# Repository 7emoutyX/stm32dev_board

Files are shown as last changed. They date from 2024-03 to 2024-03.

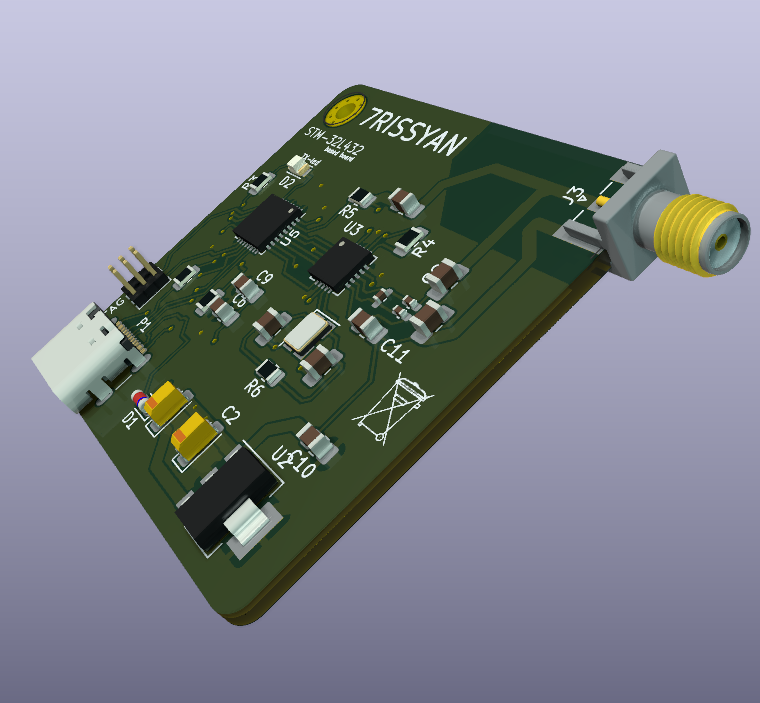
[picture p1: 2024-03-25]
Final results/33.png

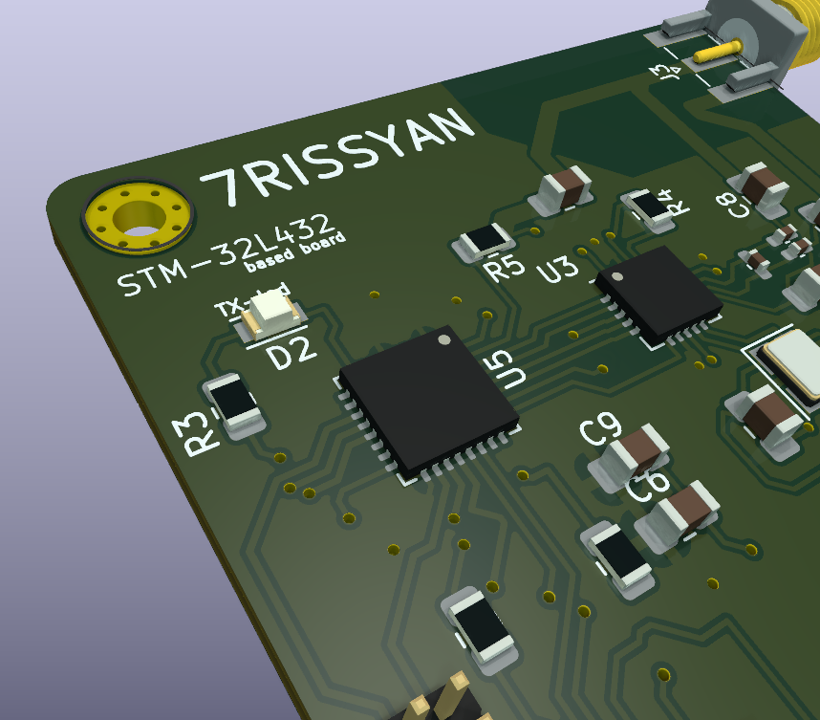
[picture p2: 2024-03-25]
Final results/44.png

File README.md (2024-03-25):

 STM32L432KBU_NRF24L01P_Development_Board

## Overview
This repository contains the KiCad project files and firmware source code for the STM32L432KBU development board integrated with the NRF24L01P module. 

## Schematic 
Final Schematic

[Download Schematic.pdf](https://github.com/7emoutyX/stm32dev_board/files/14748390/Final.Schematic.pdf)

## Layaout :  
Layaout with Fill : OFF
Layaout with Fill : ON

## Features
- Development board based on STM32L432KBU microcontroller
- Integrated NRF24L01P wireless communication module
- Antenna socket
- JTAG debug pins
- Schematics and PCB layout designed with KiCad

## Getting Started
To get started with this development board, follow these steps:

1. Clone this repository to your local machine.
2. Open the KiCad project files located in the `Documentation/Schematics` and `Documentation/PCB Layout` directories.
3. Review the schematics and PCB layout to understand the hardware design.

## Documentation
- **Schematics:** KiCad schematic files (.sch)
- **PCB Layout:** KiCad PCB layout files (.kicad_pcb)
- **Datasheets:**:
- Datasheets for STM32L432KBU : (https://www.mouser.fr/datasheet/2/389/stm32l432kb-1851151.pdf)
- Datasheets NRF24L01P  : (https://www.mouser.fr/datasheet/2/297/nRF24L01P-1187709.pdf)

## Issues
Found a bug or have a feature request? Please open an issue [here](../../issues)!

## Final results : 



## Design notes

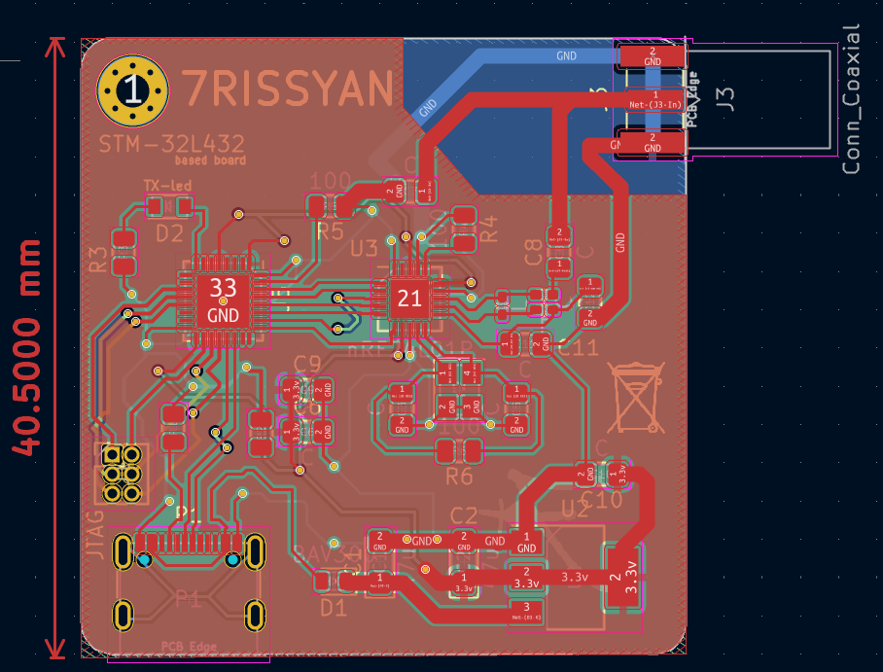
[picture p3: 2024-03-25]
Layaout/pcb2.png

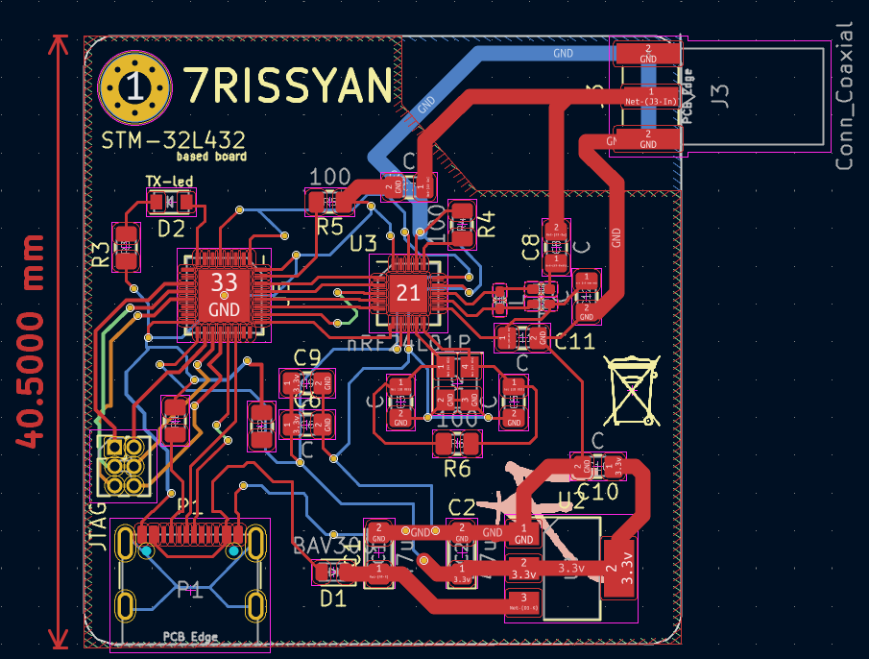
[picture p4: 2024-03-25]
Layaout/pcb.png

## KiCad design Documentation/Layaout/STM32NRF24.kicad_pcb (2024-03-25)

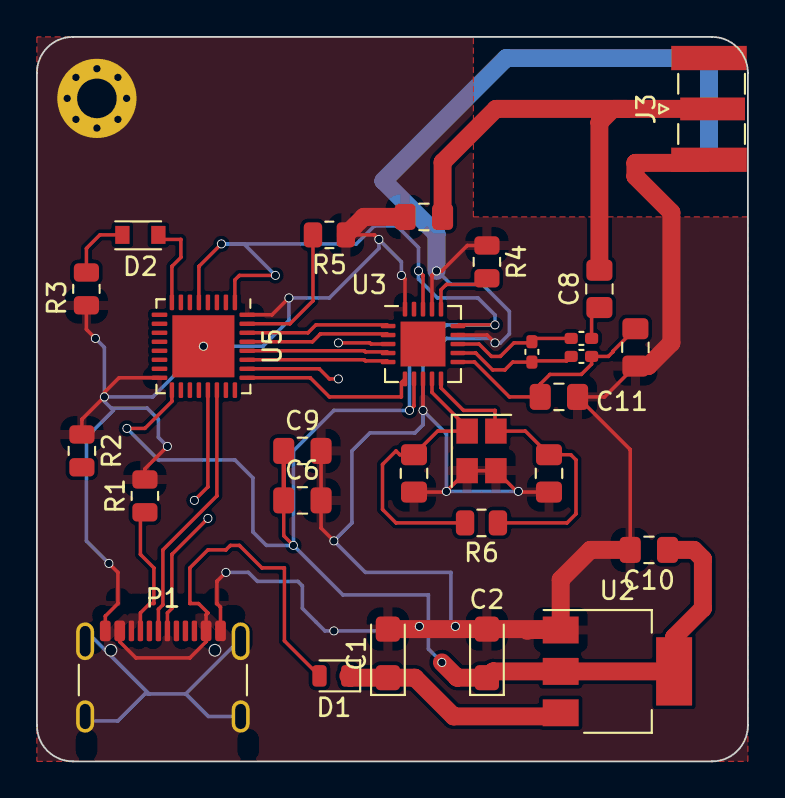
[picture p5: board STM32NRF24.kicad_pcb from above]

Board: 4 copper layers, 39.5 x 40.2 mm, 28 parts (0 on the bottom side), 24 nets.

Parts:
C1, C2: 47uF; CP_EIA-3216-18_Kemet-A
C3, C5, C6, C7, C8, C9, C10, C11, C12: C; C_0805_2012Metric_Pad1.18x1.45mm_HandSolder
D1: BAV300; D_MicroMELF
D2: LED; LED_miniPLCC_2315
J3: Conn_Coaxial; SMA_Samtec_SMA-J-P-X-ST-EM1_EdgeMount
L1, L2, L3: L; C_0402_1005Metric_Pad0.74x0.62mm_HandSolder
P1: USB_C_Plug_USB2.0; USB_C_Receptacle_GCT_USB4105-xx-A_16P_TopMnt_Horizontal
R1, R2, R3, R4, R5, R6: 100; R_0805_2012Metric
U2: LD1117S12TR_SOT223; SOT-223-3_TabPin2
U3: nRF24L01P; QFN-20-1EP_4x4mm_P0.5mm_EP2.5x2.5mm
U5: STM32L432KBUx; QFN-32-1EP_5x5mm_P0.5mm_EP3.45x3.45mm
Y2: Crystal_GND23_Small; Crystal_SMD_Abracon_ABM8AIG-4Pin_3.2x2.5mm

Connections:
3.3v: C2.1, C6.1, C9.1, C10.1, U2.2 (VO), U3.7 (VDD), U3.15 (VDD), U3.18 (VDD), U5.1 (VDD), U5.5 (VDDA), U5.17 (VDD)
D+: P1.A6 (D+), U5.22 (PA12)
D-: P1.A7 (D-), U5.21 (PA11)
GND: C1.2, C2.2, C3.2, C5.2, C6.2, C7.2, C9.2, C10.2, C11.2, C12.2, J3.2 (Ext), P1.A1 (GND), P1.A12 (GND), P1.B1 (GND), P1.B12 (GND), R1.2, R2.1, R3.1, R4.1, R5.1, U2.1 (GND), U3.8 (VSS), U3.14 (VSS), U3.17 (VSS), U3.20 (VSS), U5.16 (VSS), U5.32 (VSS), U5.33 (VSS), Y2.2, Y2.3
NRF_CE: U3.1 (CE), U5.30 (PB7)
NRF_IRQ: U3.6 (IRQ), U5.25 (PA15)
unnamed: C8.1, L3.2
unnamed: D1.2 (A), P1.A4 (VBUS), P1.A9 (VBUS), P1.B4 (VBUS), P1.B9 (VBUS)
unnamed: C1.1, D1.1 (K), U2.3 (VI)
unnamed: D2.2 (A), U5.8 (PA2)
unnamed: D2.1 (K), R3.2
unnamed: C7.1, C8.2, J3.1 (In)
unnamed: P1.A5 (CC), R1.1
unnamed: L1.1, L2.1, U3.12 (ANT1)
unnamed: L1.2, L3.1, U3.13 (ANT2)
unnamed: R4.2, U3.16 (IREF)
unnamed: C11.1, C12.1, L2.2, U3.11 (VDD_PA)
unnamed: C5.1, R6.1, U3.10 (XC1), Y2.4
unnamed: C3.1, R6.2, U3.9 (XC2), Y2.1
unnamed: R5.2, U5.31 (PH3)
SPI_CSK: U3.3 (SCK), U5.26 (PB3)
SPI_CSn: U3.2 (CSN), U5.29 (PB6)
SPI_MISO: U3.5 (MISO), U5.27 (PB4)
SPI_MOSI: U3.4 (MOSI), U5.28 (PB5)

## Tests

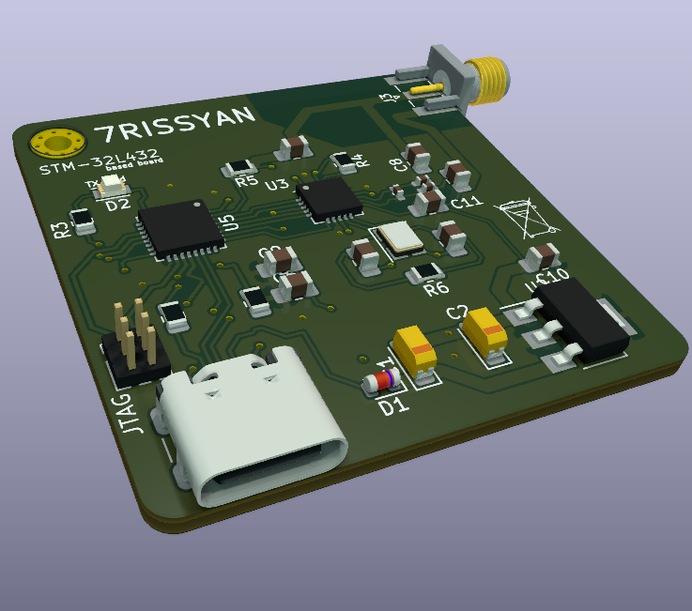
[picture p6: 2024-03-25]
Final results/Final 1.png
